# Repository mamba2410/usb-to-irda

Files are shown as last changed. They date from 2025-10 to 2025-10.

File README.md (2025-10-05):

# USB to IrDA converter board

# THIS IS UNTESTED, DO NOT BUILD YET

## What is this?

This is a USB to IrDA adapter. Plug it into a computer and it will appear as a serial/COM port.
Anything you write to that port will come out over the IR transceiver at the top, encoded using the IrDA standard.

This was made to interface with the Pokewalker, since other IrDA adapter boards are either expensive or not very sleek.

You can also plug in a UART cable if you want.
It uses the [Raspberry Pi UART/Debug spec](https://datasheets.raspberrypi.com/debug/debug-connector-specification.pdf).
Cables to adapt to 0.1" headers should be easily purchaseable online.

## Instructions

Until I/someone makes a JLC PCBA project for this, you will need to buy the parts yourself and assemble by hand.
All you should need is a soldering iron and needle-nose tweezers.
The parts have been chosen specifically so that you don't need special equipment to make.

Tips:

- Change your soldering iron tip depending on the part. Be careful, it will be hot.
    - A knife/chisel tip for the MCU, USB connector, LDO and IR transceiver might help.
    - Small chisel tip for the capacitors, LEDs and resistors.
- Use lots of flux
- The direction of LEDs matter. Unfortunately there's no easy way to tell which is the right way.
  You can check the datasheet and use a microscope to tell, or just try one way and if it doesn't light up, try the other.
- Try not to spend too much time on a single part. A few seconds at a time. Spending longer might risk damaging the component.
- Consider buying spares, especially of the passives (resistors, capacitors, LEDs).

### Board

Order from your favourite PCB fab. Files provided will be for JLC. If you want others (e.g. PCBway) then you'll have to generate them yourself from the KiCad files.

This is a 2-layer board, 1.6mm thickness, lead-free HASL finish.
Don't bother with the stencil unless you want to use a hot plate and solder paste.
You should be able to buy 5 for like $3 plus shipping.

### Parts

- IrDA transceiver x 1- TFBS4711 (TR1/TT1 for hand solder)
- MCU x 1- STM32F042K6T6
- USB connector x 1 of either:
  - 12402012E212A (Amphenol)
  - USB4215-03-A (GCT)
- 3.3V regulator x 1 - TLV1117LV33DCYR
- UART connectors x 1 - SM03B-SRSS-TB
- Buttons x 2 - B3FS1012P
- 5.1k resistors x 12 - RC0603FR-105K1L
- 47R resistor x 2 - RC0603FR-1047RL
- 0.1u capacitor x 1 - MCASE168SB5104KTNA01
- 1u capacitor x 2 - LMK107BJ105MAHT
- 4.7u capacitors x 2 - LMK107BJ475KA-T
- LEDs x 4 
  - Green/yellow (574 nm) - KG EELP41.22-PHRH-35-A8J8-20-R18 
  - Yellow (590 nm) - 150060YS83000
  - Red (624 nm) - KR EELP41.22-Q1S1-36-A8J8-020-R18
  - Amber (610 nm) - 150060AS83000 
  - Blue (465 nm) - 150060BS83000 
  - Green (527 nm) - KT EELP41.12-S2U1-25-2X4X-5-R18 
  - White - KW EELP41.RU-S1U1-3K6L-3X4X-5-R18

Checked on Mouser USA and it cost $12 plus shipping and taxes for enough to make one.
Building in quantity (10+) will significantly drop this price per unit.

There are four LEDs, TX activity, RX activity, power status and a spare. Pick and choose which colour you want.
Use [this website](https://405nm.com/wavelength-to-color/) to get an idea of the colour of each by putting in the wavelength (e.g. 590 nm).

### Enclosure

Enclosure is made using FreeCad 1.0.
An STL file will be provided to be able to 3d print.
You can either print this yourself, or get a bureau service to do it, like JLC.

You will need 4x M3 x 12mm screws and 4x M3 nuts.

### Programming

TBD

Idea is you hold the `BOOT0` button when plugging in over USB. This will trigger the DFU bootloader on the MCU.
Drag and drop the firmware onto it and wait for it to reboot.

## Development

This is currently untested.

If you want to play with the KiCad files, you can. There should be a project library called `irda` which contains custom symbols, footprints and models of the components used.

If you want to change the program, you'll have a bit of trouble since I haven't written that yet.

If you want to debug, you'll need to solder the SWD header. Its the same as the UART header.

If you want to edit the 3D files, use FreeCad 1.0 or higher.

Generating the KiKit files from the KiCad shell

```bash
kikit panelize -p kikit.json .\irda-stm32.kicad_pcb panelized\panelized.kicad_pcb
```

## License

Free to use/modify/sell. Do whatever you want with this. Just don't blame me if it doesn't work or breaks something else.

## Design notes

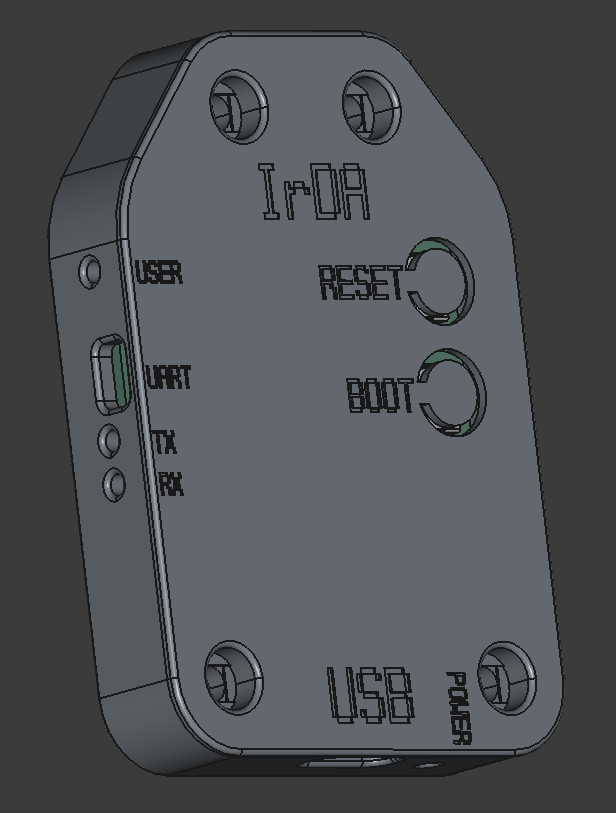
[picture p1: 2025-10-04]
assets/enclosure_front.png

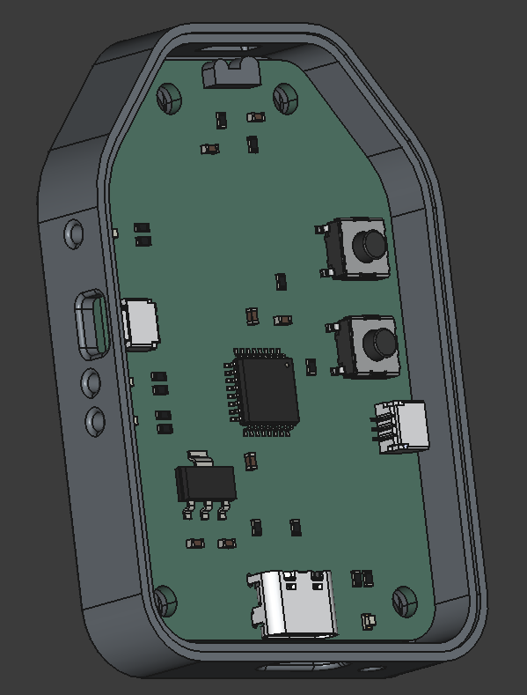
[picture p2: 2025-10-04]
assets/enclosure_board.png

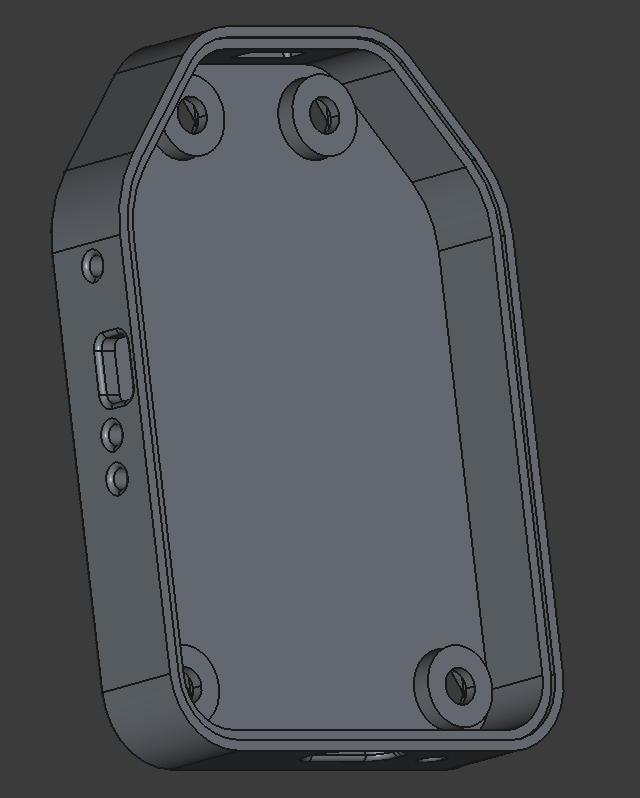
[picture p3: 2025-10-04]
assets/enclosure_inner.png

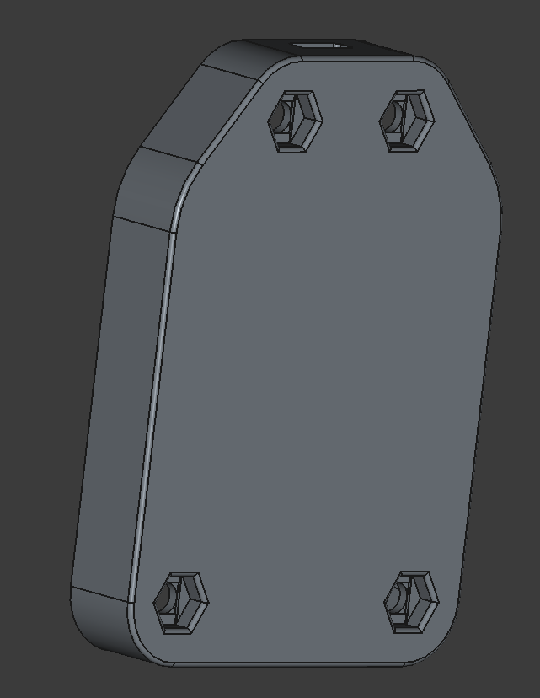
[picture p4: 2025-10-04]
assets/enclosure_back.png

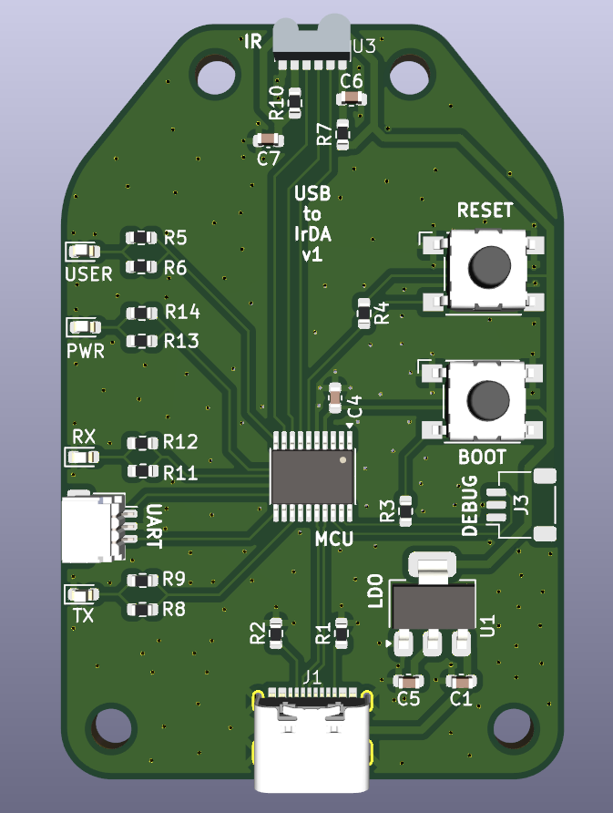
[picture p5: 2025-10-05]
assets/board_front.png

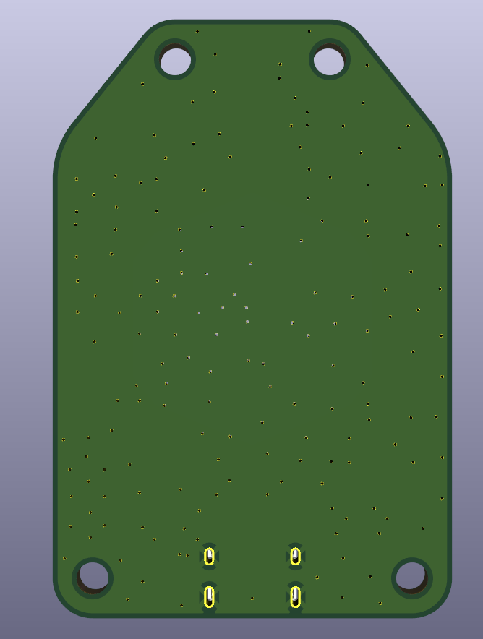
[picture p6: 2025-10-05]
assets/board_rear.png

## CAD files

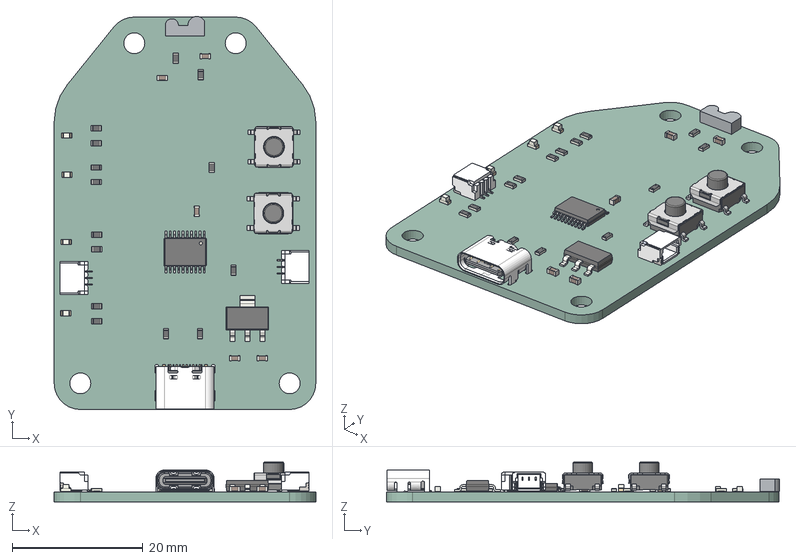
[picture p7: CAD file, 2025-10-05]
kicad/irda-stm32.step
40.0 x 60.1 x 6.09 mm
SOT-223
LED_0603_1608Metric x 4
R_0603_1608Metric x 14
USB4215-03-A_PART1
USB4215-03-A_PART2
C_0603_1608Metric x 5
B3FS-1012P x 2
SM03B-SRSS-TB_LF__SN_ x 2
TFBS4711
TSSOP-20_4.4x6.5mm_P0.65mm
irda-stm32_PCB

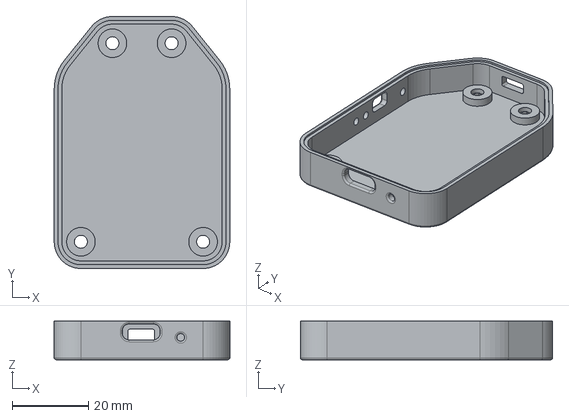
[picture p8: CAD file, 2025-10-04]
mechanical/enclosure-Base.step
46.0 x 66.0 x 10.1 mm

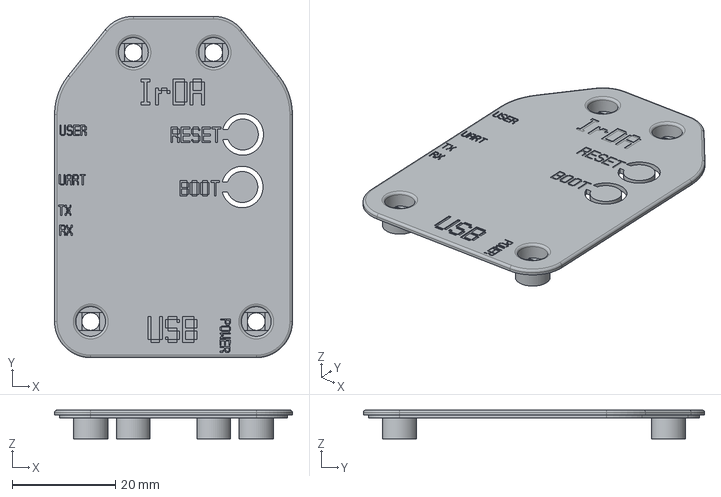
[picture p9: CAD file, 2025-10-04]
mechanical/enclosure-Lid.step
46.0 x 66.0 x 5.58 mm

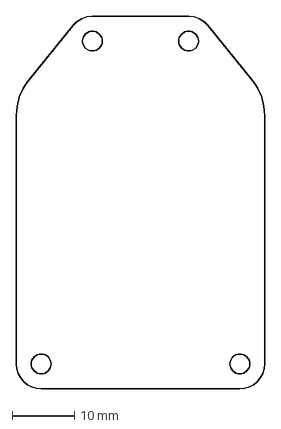
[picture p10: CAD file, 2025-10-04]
mechanical/board_outline.dxf
40.0 x 60.0 mm

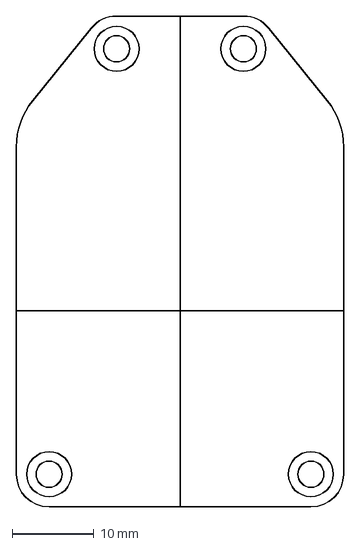
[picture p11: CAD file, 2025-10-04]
mechanical/board_outline_references.dxf
40.0 x 60.0 mm

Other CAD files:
mechanical/enclosure.FCStd
mechanical/enclosure-Base.stl
mechanical/enclosure-Lid.stl

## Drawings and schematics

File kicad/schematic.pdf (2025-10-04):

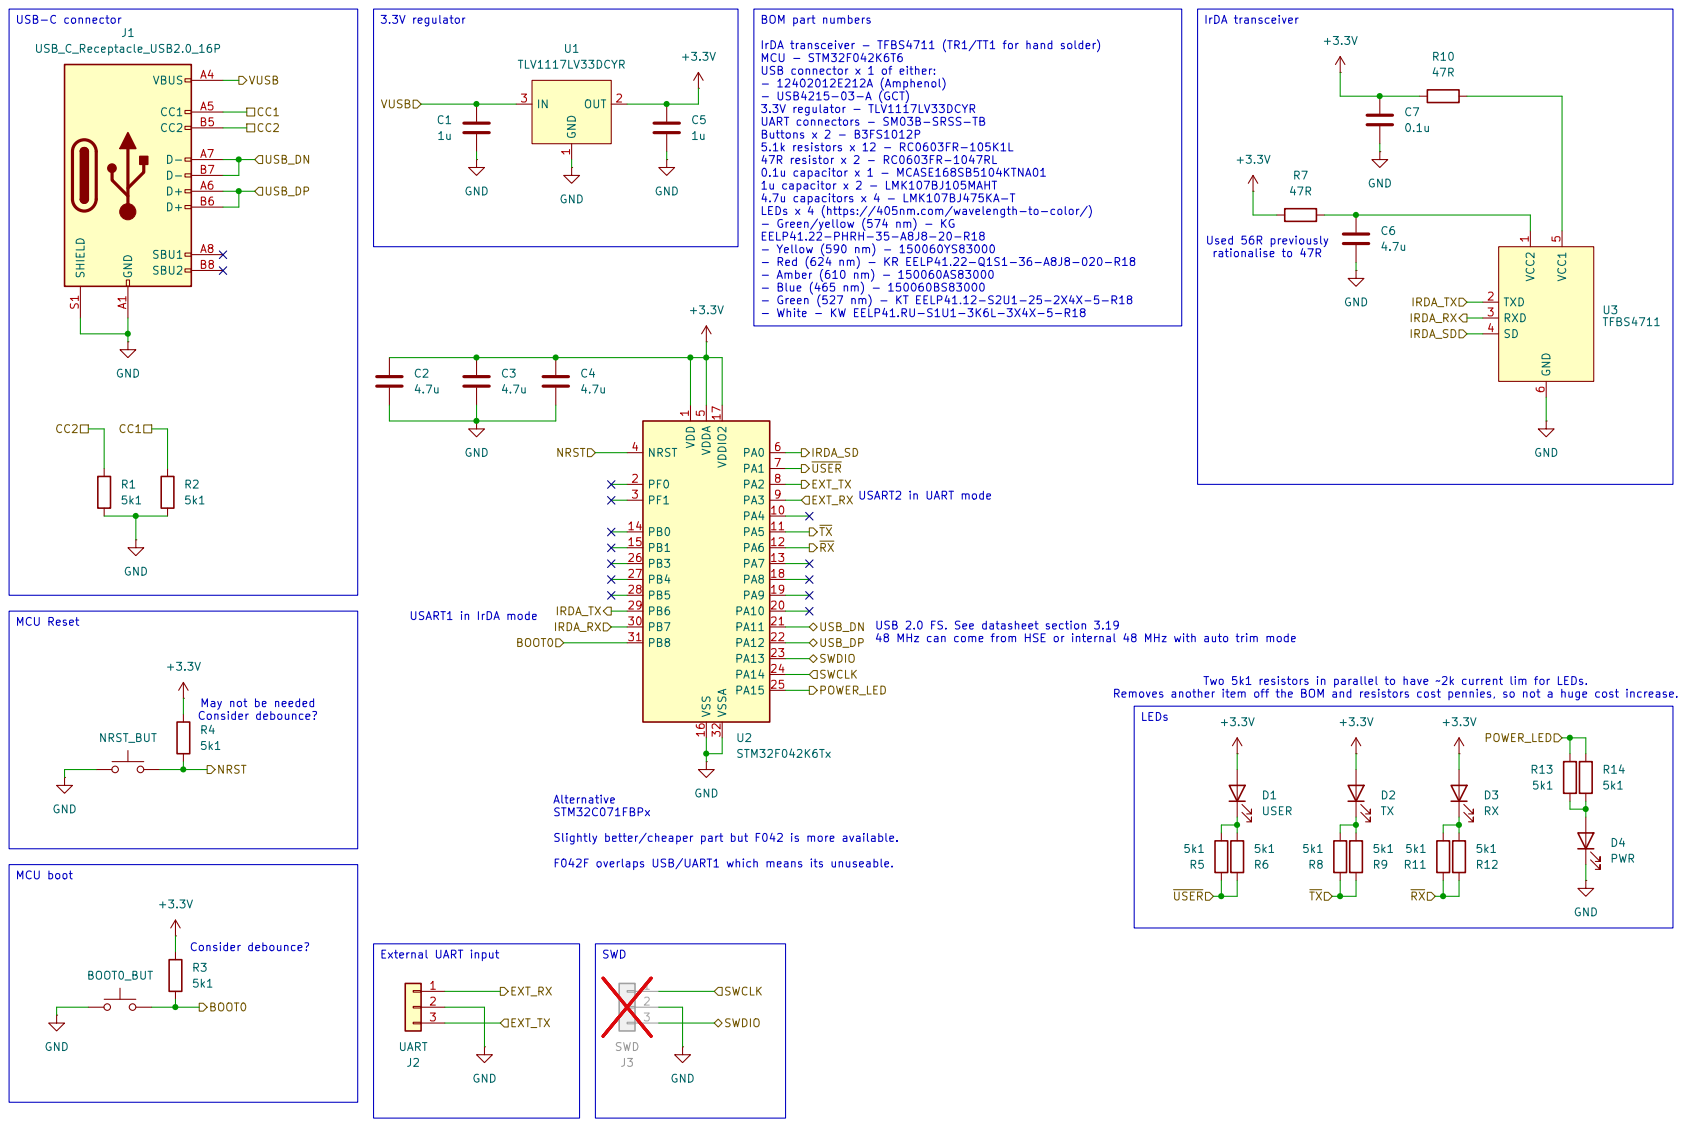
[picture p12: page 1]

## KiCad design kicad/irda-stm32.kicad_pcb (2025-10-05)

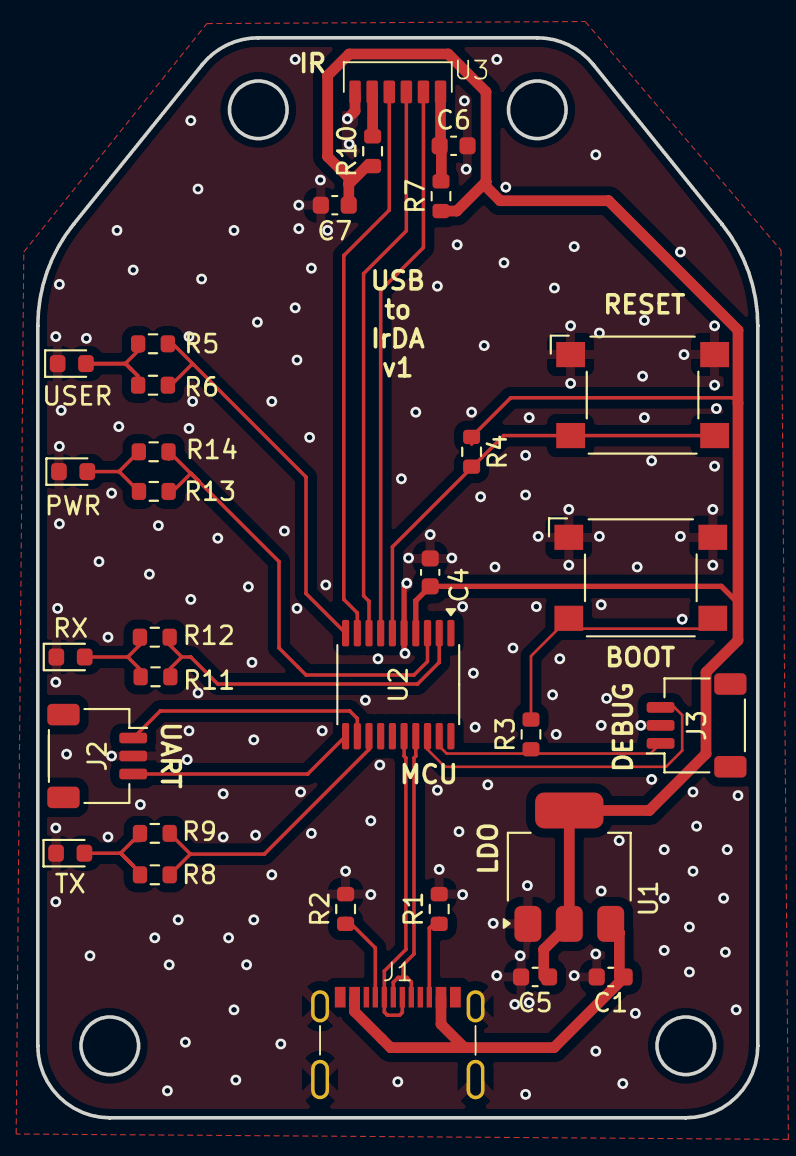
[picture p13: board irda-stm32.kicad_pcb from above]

Board: 2 copper layers, 40.0 x 60.0 mm, 31 parts (0 on the bottom side), 26 nets.

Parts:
C1, C5: 1u; C_0603_1608Metric
C4, C6: 4.7u; C_0603_1608Metric
C7: 0.1u; C_0603_1608Metric
D1: USER; LED_0603_1608Metric
D2: TX; LED_0603_1608Metric
D3: RX; LED_0603_1608Metric
D4: PWR; LED_0603_1608Metric
J1: USB_C_Receptacle_USB2.0_16P; GCT_USB4215_03_A
J2: UART; JST_SH_SM03B-SRSS-TB_1x03-1MP_P1.00mm_Horizontal
J3: SWD; JST_SH_SM03B-SRSS-TB_1x03-1MP_P1.00mm_Horizontal
R1, R2, R3, R4, R5, R6, R8, R9, R11, R12, R13, R14: 5k1; R_0603_1608Metric
R7, R10: 47R; R_0603_1608Metric
SW1: BOOT0_BUT; SW_SPST_Omron_B3FS-100xP
SW2: NRST_BUT; SW_SPST_Omron_B3FS-100xP
U1: TLV1117LV33DCYR; SOT-223-3_TabPin2
U2: STM32C071FBPx; TSSOP-20_4.4x6.5mm_P0.65mm
U3: TFBS4711; TFBS4711-TR

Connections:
+3.3V: C4.1, C5.1, C7.1, R4.1, R7.1, R10.1, U1.2 (OUT), U2.4 (VDD)
/CC1: J1.A5 (CC1), R2.1
/CC2: J1.B5 (CC2), R1.1
/EXT_RX: J2.1, U2.12 (PA5)
/EXT_TX: J2.3, U2.11 (PA4)
/IRDA_RX: U2.8 (PA1), U3.3 (RXD)
/IRDA_SD: U2.9 (PA2), U3.4 (SD)
/IRDA_TX: U2.7 (PA0), U3.2 (TXD)
/NRST: R4.2, SW2.2, U2.6 (PF2)
/POWER_LED: R13.1, R14.1, U2.3 (PC15)
/RX_LED: R11.1, R12.1, U2.2 (PC14)
/SWCLK: J3.1, R3.1, U2.19 (PA14/PA15)
/SWDIO: J3.3, U2.18 (PA13)
/TX_LED: R8.1, R9.1, U2.13 (PA6)
/USB_DN: J1.A7 (D-), J1.B7 (D-), U2.16 (PA11)
/USB_DP: J1.A6 (D+), J1.B6 (D+), U2.17 (PA12)
/USER_LED: R5.1, R6.1, U2.10 (PA3)
/VUSB: C1.1, J1.A4 (VBUS), J1.A9 (VBUS), J1.B4 (VBUS), J1.B9 (VBUS), U1.3 (IN)
GND: C1.2, C4.2, C5.2, C6.2, C7.2, D1.1 (K), D2.1 (K), D3.1 (K), D4.1 (K), J1.A1 (GND), J1.A12 (GND), J1.B1 (GND), J1.B12 (GND), J1.S1 (SHIELD), J2.2, J3.2, R1.2, R2.2, SW1.1, SW2.1, U1.1 (GND), U2.5 (VSS), U3.6 (GND)
unnamed: D1.2 (A), R5.2, R6.2
unnamed: D2.2 (A), R8.2, R9.2
unnamed: D3.2 (A), R11.2, R12.2
unnamed: D4.2 (A), R13.2, R14.2
unnamed: R3.2, SW1.2
unnamed: R10.2, U3.5 (VCC1)
unnamed: C6.1, R7.2, U3.1 (VCC2)

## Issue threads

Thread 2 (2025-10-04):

Change MCU to STM32C071FBP6

mamba2410, 2025-10-04:
It actually can work, I'm just dumb.

PF2 = NRST

PA14 = BOOT0 / SWCLK

UART1 doesn't overlap USB, unlike F042Fxxx

Prices:

- [C071KBT6](https://www.mouser.co.uk/ProductDetail/STMicroelectronics/STM32C071KBT6?qs=iLKYxzqNS77e9byF5PxJcg%3D%3D) £1.84/£1.19
- [C071FBP6](https://www.mouser.co.uk/ProductDetail/STMicroelectronics/STM32C071FBP6?qs=iLKYxzqNS75swQ0K3xgx5w%3D%3D) £1.77/£1.13
- [F042K6T6](https://www.mouser.co.uk/ProductDetail/STMicroelectronics/STM32F042K6T6?qs=4b8myOmUP%252BsYBBEp2ZwbyQ%3D%3D) £2.44/£1.85

Closed 2025-10-05.

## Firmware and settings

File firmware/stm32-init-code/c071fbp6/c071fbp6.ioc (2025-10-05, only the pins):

Mcu.UserName=STM32C071FBPx
PA0.GPIO_Label=IRDA_TX
PA0.Signal=USART1_TX
PA1.GPIO_Label=IRDA_RX
PA1.Signal=USART1_RX
PA13.Signal=DEBUG_SWDIO
PA14-BOOT0.Signal=DEBUG_SWCLK
PA2.GPIO_Label=IRDA_SD
PA2.Signal=GPIO_Output
PA3.GPIO_Label=USER_LED
PA3.Signal=GPIO_Output
PA4.Signal=USART2_TX
PA5.Signal=USART2_RX
PA6.GPIO_Label=TX_LED
PA6.Signal=GPIO_Output
PC14-OSCX_IN(PC14).GPIO_Label=RX_LED
PC14-OSCX_IN(PC14).Signal=GPIO_Output
PC15-OSCX_OUT(PC15).GPIO_Label=POWER_LED
PC15-OSCX_OUT(PC15).Signal=GPIO_Output
PF2-NRST.GPIO_Label=NRST
PF2-NRST.Signal=GPIO_Input

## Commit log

2025-10-04 add enclsoure
    [enclosure-Base.step, enclosure-Base.stl, enclosure-Lid.step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]
2025-10-05 update kicad, idk
    [irda-stm32.kicad_pcb, irda-stm32.kicad_sch]
2025-10-05 update PCB for c071fbp6
    [irda-stm32.kicad_pcb, irda-stm32.kicad_sch]
2025-10-05 widen resistor spacing
    [irda-stm32.kicad_pcb, irda-stm32.step]
2025-11-23 fix BOOT0 button and USB ground
2025-11-23 add blank stm32cube project
2025-11-23 explicitly set RDP level to stop device from bricking itself
2026-02-08 add lcsc/jlc part numbers and fix ir filters
